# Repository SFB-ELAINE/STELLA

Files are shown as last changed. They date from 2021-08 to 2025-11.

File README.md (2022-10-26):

# The SofTware dEfined impLantabLe modular plAtform (STELLA) for preclinical deep brain stimulation

## Stimulation Platform

We aimed to develop an innovative neurostimulator that significantly increases animal welfare and DBS studies' scientific value. 

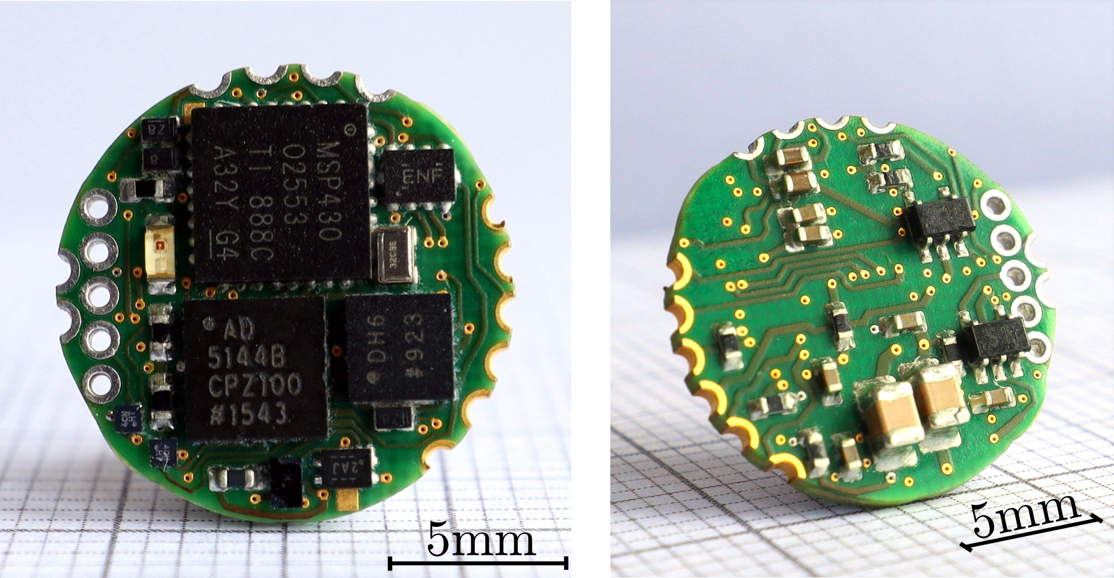
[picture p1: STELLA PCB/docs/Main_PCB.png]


Further details can be found at:

Franz Plocksties, Maria Kober, Christoph Niemann, Jakob Heller, Mareike Fauser, Martin Nüssel, Felix Uster, Denise Franz, Monique Zwar, Anika Lüttig, Justin Kröger, Jörg Harloff, Axel Schulz, Angelika Richter, Rüdiger Köhling, Dirk Timmermann, Alexander Storch:
The software defined implantable modular platform (STELLA) for preclinical deep brain stimulation research in rodents
In Journal of Neural Engineering, Vol. 18, Iss. 5, ISSN: 1741-2560, pp. 1-20, DOI: 10.1088/1741-2552/ac23e1, September 2021. https://iopscience.iop.org/article/10.1088/1741-2552/ac23e1

Hardware, software, and additional materials are available from here: [STELLA MAIN PCB](https://github.com/SFB-ELAINE/STELLA/tree/main/STELLA%20PCB)

## RF Shield

To link STELLA to the outside world, we have developed an energy-efficient RF Shield that operates in the ISM band. This shield can be piggybacked by STELLA, achieving a compact design. 

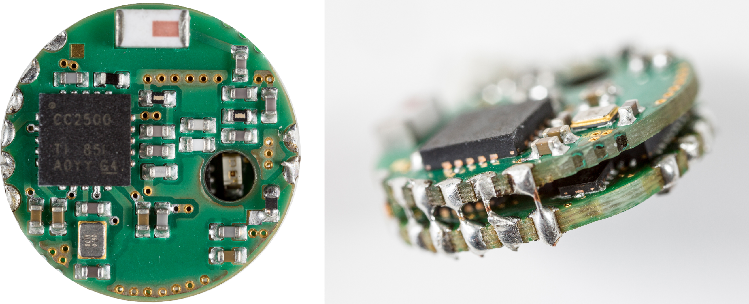
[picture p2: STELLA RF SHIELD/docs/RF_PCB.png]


Further details can be found at:

Franz Plocksties, Obaid Ullah Shah, Felix Uster, Munawar Ali, Maximilian Koschay, Maria Kober, Alexander Storch, Dirk Timmermann:
Energy-efficient modular RF interface for fully implantable electrical devices in small rodents
In Proceedings of the IEEE Biomedical Circuits and Systems Conference (BioCAS), pp. 1-6, DOI:10.1109/BioCAS49922.2021.9645022, Berlin, Deutschland, Oktober 2021. https://ieeexplore.ieee.org/document/9645022

Hardware, software, and additional materials are available from here: [STELLA RF SHIELD](https://github.com/SFB-ELAINE/STELLA/tree/main/STELLA%20RF%20SHIELD)

## Comparison of existing neurostimulators with STELLA

| | Ewing (2013) [56] | Kouzani (2017) [27] | Kölbl (2016) [26] | Fluri (2017) [24] | Pinnell (2018) [29] | Adams (2019) [21] | Harnack (2008) [32] | Fleischer (2020) [57] | de Haas (2012) [31] | Hentall (2013) [33] | Millard (2007) [34] | Forni (2012) [25] | Alpaugh (2019) [30] | Liu (2017) [28] | Arfin (2009) [22] | STELLA |
|---|---|---|---|---|---|---|---|---|---|---|---|---|---|---|---|---|
| Current amplitude (µA) | 13-1000 | 200 | 26-2036 | 10-500 | 20-2000 | -625 | 50-600 | up to 300 | 20-100 | 20-100 | 100-500 | 50-120 | 149 | 200-500 | 10-1000 | 42-100 |
| Pulse-width (µs) | 1µs-100% DC‡ | 90 | 0.5µs-100% DC‡ | 60-500 | 10µs-100% DC‡ | 20 (min) | 52 | 60-500 | 60 | 100-1000 | 25-250 | 0-80 | 103/111 | 30-1400 | 180 | 1µs-100% DC‡ |
| Frequency (Hz) | 2-500 | 130 | 10-300 | 10-200 | 0.1-5000 | 5000 (max) | 131 | 10-500 | 131 | 8, 16 or 24 | 50-5000 | 0-130 | 130 | 1-200 | 1400 (max) | 10-5000 |
| Inter-pulse delay (µs) | n/a | n/a | 60 | n/a | 0-pulse period | n/a | n/a | n/a | 200 | n/a | n/a | n/a | 103 | n/a | n/a | n/a |
| Compliance voltage (V) | 20 | 3 (battery) | 17 | 3.1 (battery) | 12 | 10 | 18 | 3.1 (battery) | 4.65 (battery) | 34 | 5 | 6 (battery) | 2,1 | 3 (battery) | 5 | 2.2-2.8 |
| No.  of channels | 2 | 1 | 1 | 1 | 2 | 1 | 1 | 1 | 2 | 1 | 1 | 1 | 1 | 1 | 4 | 2 |
| Charge balancing | Passive | Passive | Active | Passive | Active/Passive | Active | Active | Passive | Active | Passive | Active | n/a | Active | Passive | Active | Passive |
| Lifetime (DBS-on) | 10 days | 22 days | 6 days | 30 days | 30 hours | 9 hours | 28 days | 30 days | 10 hours | n/a (rests) | ∞ | 7 | 30 days | 3 months | 12 days | 126 days (CR1216), 241 days (CR1225) ¤ |
| Type of battery | ICP521630PM | CR2032 | 3xp675 | 2xV364 | CR1225 | CR2032 | 2xSR48 | 2xV364 | 3xSR416 | 2xSR41 | none, energy provided through inductive cage | 2xCR1220 | 2xSR48 | CR2032 | 2xML614 | CR1216, CR1220, CR1225, CR2032□ |
| Battery weight (g) | 5,4 | 3 | 3x1.8 | 2x0.3 | 0.9 | 3 | 2x1.1 | 2x0.3 | 3x0.13 | 2x0.6 | - | 2x0.8 | 2x1.1 | 3 | 2x0.16 | 0.6 (CR1216), 0.9 (CR1225) □ |
| PCB weight (g) | n/a | 0.92 | n/a | n/a | 0.8 | Feb 18 | n/a | n/a | n/a | n/a | n/a | n/a | n/a | n/a | n/a | 0.6 |
| Total stimulator weight (g) | 11.5¶ | 4.75§ | 13.8¶ | 2.5§ | 2.8¶ | 5§ | 13¶ | 2.8§ | 2.1¶ | 2¶ | 2.5{ | 5.6{/7.4¶ | 4.7¶ | 6§/16¶ | 1.3§ | 2.6 (CR1216), 4 (CR1225)¶ □ |
| Battery volume (mm3) | 3052 | 1000 | 3x550 | 2x70 | 300 | 1000 | 2x260 | 2x70 | 3x30 | 2x160 | - | 2x250 | 2x260 | 1000 | 2x50 | 200 (CR1216),300 (CR1225) □ |
| PCB size (mm) | n/a | 15x18x3* | 26x12x3* | n/a | Ø12.5x5 | 30x25x3* | 35x17.1x3* | 10x10x1 | 25x8x3* | n/a | n/a | 28x9x3* | n/a | Ø20x4 | 13x13x3* | Ø13x3.3 |
| PCB volume (mm3) | 2228 | 810 | 936 | 1477 | 613 | 2250 | 1796 | 130 | 600 | 688 | n/a | 756 | n/a | 1256 | 507 | 438 |
| PCB + battery volume (mm3)  | 5280 | 1810 | 2586 | 1617 | 913 | 3250 | 2316 | 270 | 690 | 1008 | - | 1256 | n/a | 2256 | 607 | 638 (CR1216), 738 (CR1225) □ |
| Total stimulator size (mm)  | 33x20x8¶ | 15x18x10*§ | 30x20x24*¶ | 21x11x7§ | Ø19.2x12.4¶ | 32.5x28x8§ | 38.5x20x13.5¶ | n/a | Ø8x30¶ | 18x8x7¶ | 14x12x6{ | 15x28x7¶ | n/a | Ø20x8¶ | n/a | Ø15.5×7.5 (CR1216), Ø17.0×9.0 (CR1225)¶ □ |
| Control medium | Magnet | Pushbutton | n/a | Jumper | Magnet | Magnet | Electromagn. | Magnet | Magnet | Magnet | Electromagn. | n/a | n/a | Electromagn. | Electromagn. | Magnet◆ |
| Output medium | Visual LED | Visual LED | n/a | Visual LED | Visual LED | Visual LED | Electromagn. | Visual LED | IR LED | IR LED | Visual LED | n/a | Visual LED | Electromagn. | Visual LED | Visual LED◆ |
| Status readout | ♣ | Programming status  | n/a | On/Off/♠ | On/Off | On/Off/♣ | Program var. | On/Off | On/Off/♠ | Program var. | On/Off | n/a | ♣ | On/Off/♣♠ | On/Off | On/Off/♣♠◆ |
| Mounting | Head or Back | Back | Head | Head | Head | Back | Implant | Implant | Head + Implant | Implant | Implant + cage | Head | Implant | Head | Head | Implant |
| Open source† | No | No | No | No | Complete | No | No | No | No | No | Incomplete | No | No | No | Incomplete | Complete |

*Estimated from photographic scale <br />
‡Duty Cycle <br />
Including §battery, {housing, ¶both <br />
†Including all design/layout/firmware files and datasets for reproduction <br />
¤ Refers to the stimulation parameters (1x100 µA, 130 Hz, 60 µs) for LPM3 at a boost voltage of 3.1 V  <br />
□ Highly flexible regarding needed stimulation time and rodent’s size and weight <br />
♣Battery voltage / ♠load impedance out of range indication <br />
◆ Extendable by inter-module communication <br />

## License

This project is licensed under the terms of GNU General Public License v3.0

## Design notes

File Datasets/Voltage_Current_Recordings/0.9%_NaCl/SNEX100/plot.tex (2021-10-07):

\documentclass[tikz]{standalone}

\usepackage{tikz}
\usepackage{circuitikz}
\usepackage{pgfplots}
\pgfplotsset{compat=1.14}

\pgfplotsset{
    compat=1.3, 
    every axis/.append style={scale only axis,
    height=2.25cm, width=2.5cm, xmin=-1, xmax=120,grid=major, x grid style={lightgray!92.02614379084967!black},
      y grid style={lightgray!92.02614379084967!black},tick align=outside, tick pos=left}
}

\pgfplotsset{every tick label/.append style={font=\footnotesize}, label style={font=\footnotesize}}
%\pgfplotsset{yticklabel style={text width=1em,align=right}}

\begin{document}
\begin{tikzpicture}
\definecolor{color0}{rgb}{0.12156862745098,0.466666666666667,0.705882352941177}

%%%%%%%%%%%%%%%%%%%%%%%%%%%%
%%%%%%%%  SNEX 100  %%%%%%%%
%%%%%%%%%%%%%%%%%%%%%%%%%%%%

%%%%%%% VOLTAGE %%%%%%%%

    \begin{axis}[%
    name=plot1,
    xticklabels={,,},
  %  xlabel={Time [$\mu$s]},
    ylabel={Voltage [V]},
    yticklabel style={text width=2em, align=right},
    xmin=-10,
    xmax=130,
   % ytick = {0, 0.4, 0.8},
    ymin=-0.1,
   ymax=0.8,
]
    \addplot[line width=1.0pt, color=color0] table [x=Time/us, y=Voltage/V, col sep=comma] {snex100_voltage_50uA_saline_no_discharge_resistance.csv};

    \addplot[line width=1.2pt, color=orange, dotted] table [x=Time/us, y=Voltage/V, col sep=comma] {snex100_voltage_50uA_saline_digital60_resistance.csv};
    \end{axis}

    \begin{axis}[%
    name=plot2,
  %  xlabel={Time [$\mu$s]},
   yticklabels={,,},
   xticklabels={,,},
    xmin=-10,
    xmax=130,
    ymin=-0.1,
    ymax=0.8,
    at=(plot1.right of south east), anchor=left of south west,
    ]
    \addplot[line width= 1.0pt, color=color0] table [x=Time/us, y=Voltage/V, col sep=comma] {snex100_voltage_100uA_saline_no_discharge_resistance.csv};

    \addplot[line width=1.2pt, color=orange, dotted] table [x=Time/us, y=Voltage/V, col sep=comma] {snex100_voltage_100uA_saline_digital60_resistance.csv};
    \end{axis}
    
%%%%%%% CURRENT %%%%%%%%
    
        \begin{axis}[%
    name=plot5,
    xlabel={Time [$\mu$s]},
    ylabel={Current [$\mu$A]},
    yticklabel style={text width=2em, align=right},
    xmin=-10,
    xmax=130,
    ymin=-380,
    ymax=130,
    ytick = {-200, 0, 50, 100},
  %  yticklabel style={rotate=-10},
   at=(plot1.below south west), anchor=above north west,
]
    \addplot[line width=1.0pt, color=color0] table [x=Time/us, y=Current/uA, col sep=comma] {snex100_current_50uA_saline_no_discharge_resistance.csv};

    \addplot[line width=1.2pt, color=orange, dotted] table [x=Time/us, y=Current/uA, col sep=comma] {snex100_current_50uA_saline_digital60_resistance.csv};
    \end{axis}
    
    \begin{axis}[%
    name=plot6,
    yticklabels={,,},
    xlabel={Time [$\mu$s]},
    xmin=-10,
    xmax=130,
    ymin=-380,
    ymax=130,    
    extra y ticks = {100},
    at=(plot5.right of south east), anchor=left of south west,
]
    \addplot[line width= 1.0pt, color=color0] table [x=Time/us, y=Current/uA, col sep=comma] {snex100_current_100uA_saline_no_discharge_resistance.csv};

    \addplot[line width=1.2pt, color=orange, dotted] table [x=Time/us, y=Current/uA, col sep=comma] {snex100_current_100uA_saline_digital60_resistance.csv};
    \end{axis}
    
%%%%%%%%%%%%%%%%%%%%%%%%%%%%
%%%%%%%%  Unipolar  %%%%%%%%
%%%%%%%%%%%%%%%%%%%%%%%%%%%%

%%%%%%% VOLTAGE %%%%%%%%

    \begin{axis}[%
    name=plot3,
    yticklabels={,,},
    xticklabels={,,},
%    xlabel={Time [$\mu$s]},
    %ylabel={Voltage [V]},
    xmin=-10,
    xmax=120,
    ymin=-0.1,
    ymax=0.8,
    at=(plot2.right of south east), anchor=left of south west,
    ]
    \addplot[line width= 1.0pt, color0] table [x=Time/us, y=Voltage/V, col sep=comma] {unipolar_voltage_50uA_saline_no_discharge_resistance.csv};

    \addplot[line width=1.2pt, color=orange, dotted] table [x=Time/us, y=Voltage/V, col sep=comma] {unipolar_voltage_50uA_saline_digital50_resistance.csv};

    \end{axis}
    
    \begin{axis}[%
    name=plot4,
    yticklabels={,,},
    xticklabels={,,},
%    xlabel={Time [$\mu$s]},
    %ylabel={Voltage [V]},
    xmin=-10,
    xmax=120,
    ymin=-0.1,
    ymax=0.8,
    at=(plot3.right of south east), anchor=left of south west,
    ]
    \addplot[line width= 1.0pt, color0] table [x=Time/us, y=Voltage/V, col sep=comma] {unipolar_voltage_100uA_saline_no_discharge_resistance.csv};

    \addplot[line width=1.2pt, color=orange, dotted] table [x=Time/us, y=Voltage/V, col sep=comma] {unipolar_voltage_100uA_saline_digital50_resistance.csv};

    \end{axis}
    
%%%%%%% CURRENT %%%%%%%%
   
    \begin{axis}[%
    name=plot7,
    yticklabels={,,},
    xlabel={Time [$\mu$s]},
    %ylabel={Current [$\mu$A]},
    xmin=-10,
    xmax=120,
    ymin=-380,
    ymax=130,
    extra y ticks = {50},
    at=(plot6.right of south east), anchor=left of south west,
    ]
    \addplot[line width= 1.0pt, color0] table [x=Time/us, y=Current/uA, col sep=comma] {unipolar_current_50uA_saline_no_discharge_resistance.csv};

    \addplot[line width= 1.2pt, color=orange, dotted] table [x=Time/us, y=Current/uA, col sep=comma] {unipolar_current_50uA_saline_digital50_resistance.csv};

    \end{axis}
    
    \begin{axis}[%
    name=plot8,
    yticklabels={,,},
    xlabel={Time [$\mu$s]},
    xmin=-10,
    xmax=120,
    ymin=-380,
    ymax=130,
    extra y ticks = {100},
    at=(plot7.right of south east), anchor=left of south west,
    ]
    \addplot[line width= 1.0pt, color0] table [x=Time/us, y=Current/uA, col sep=comma] {unipolar_current_100uA_saline_no_discharge_resistance.csv};

    \addplot[line width= 1.2pt, color=orange, dotted] table [x=Time/us, y=Current/uA, col sep=comma] {unipolar_current_100uA_saline_digital50_resistance.csv};

    \end{axis}

\draw [dashed, line width=0.8pt] (5.6,2.7) -- (5.6,-3.8);   

\node[align=center] at (2.7,2.5) {\small \textbf{Bipolar}};
\node[align=center] at (8.5,2.5) {\small \textbf{Unipolar}};

\node[align=center] at (2.25,2) {\footnotesize (a)};
\node[align=center] at (2.25,-0.7) {\footnotesize (b)};
\node[align=center] at (5.15,2) {\footnotesize (c)};
\node[align=center] at (5.15,-0.7) {\footnotesize (d)};
\node[align=center] at (8.05,2) {\footnotesize (e)};
\node[align=center] at (8.05,-0.7) {\footnotesize (f)};
\node[align=center] at (10.95,2) {\footnotesize (g)};
\node[align=center] at (10.95,-0.7) {\footnotesize (h)};

\end{tikzpicture}
\end{document}

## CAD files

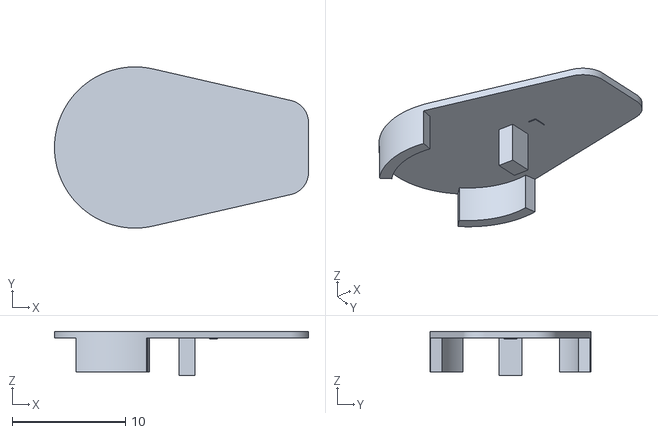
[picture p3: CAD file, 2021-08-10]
STELLA RF SHIELD/Encapsulation/Cap.stl
22.4 x 14.2 x 3.90

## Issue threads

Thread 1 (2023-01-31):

Parts list for PCB

skeltoh, 2023-01-31:
I am interested in building this - do you have a list of specific parts/manufacturers you used to assemble the pcb? I'm not sure if small details like thick/thin film resistors are important, and wanted to replicate it as closely as possible.

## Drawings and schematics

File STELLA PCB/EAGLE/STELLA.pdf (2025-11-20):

# A1 GND B¹ VCC A²

A

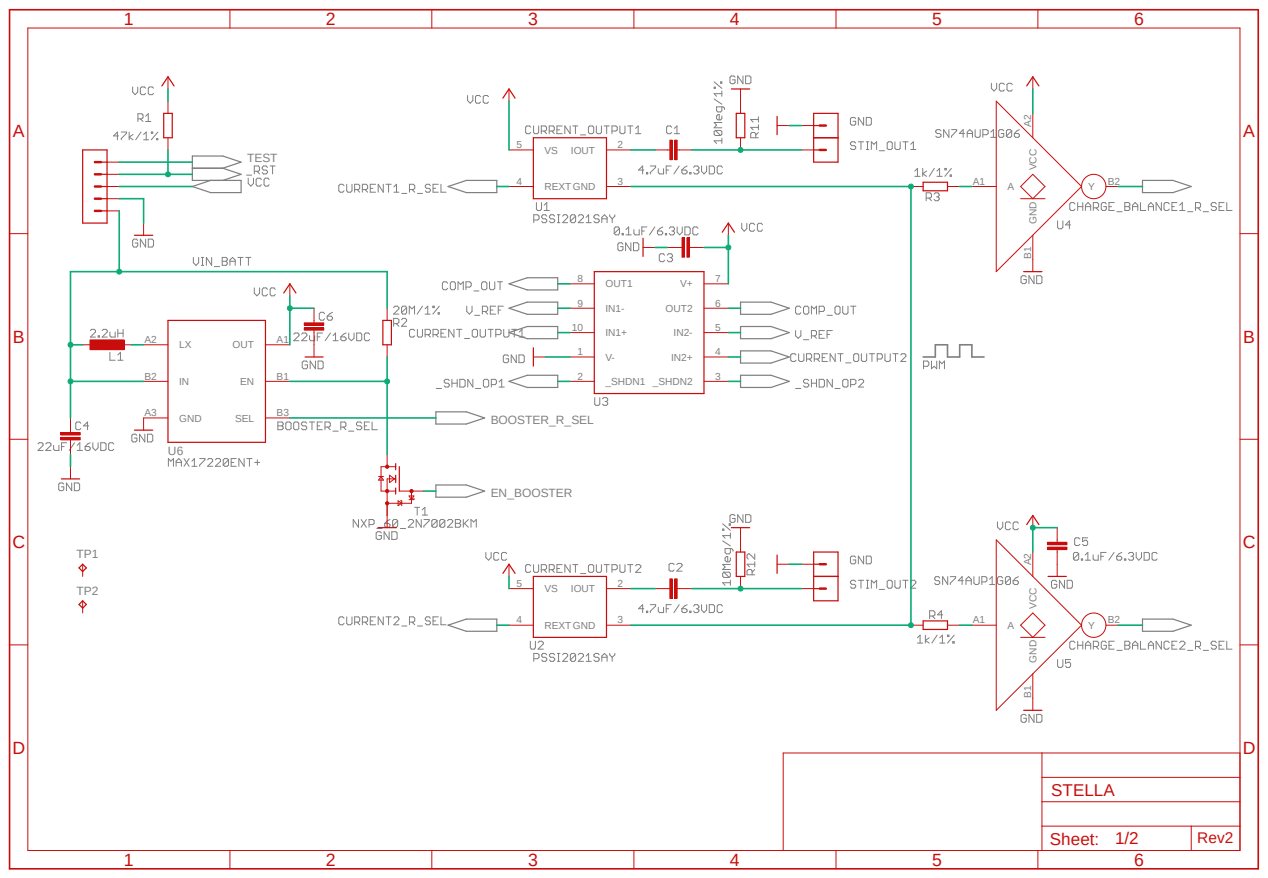
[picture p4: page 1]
GND; IOUT; REXT 4; OUT; SEL; GND A3; OUT1 8; OUT2; _SHDN1 2; _SHDN2; GND B¹ VCC A²; BOOSTER_R_SEL; EN_BOOSTER; TEST; Sheet:; Rev2; STELLA

# _WP 20 PAD 25

A

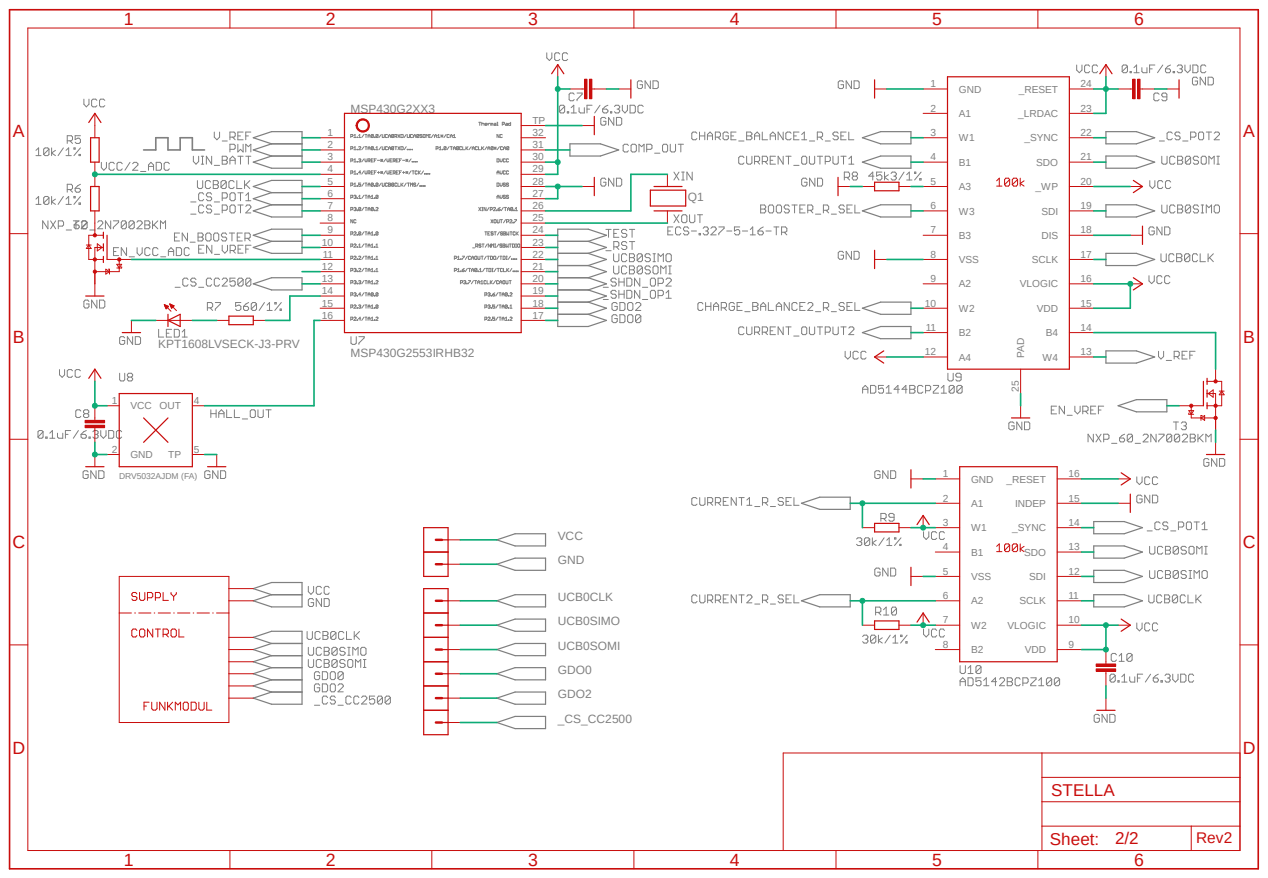
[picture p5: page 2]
MSP430G2553IRHB32; MSP430G2XX3; KPT1608LVSECK-J3-PRV; DRV5032AJDM (FA); DIS; GND 1; SCLK; SDI; SDO; VDD; VLOGIC; VSS 8; _LRDAC; _RESET; _SYNC; INDEP; VSS 5; GND 2; OUT 4; VCC 1; VCC; GND; UCB0CLK; UCB0SOMI; UCB0SIMO; GDO0; GDO2; Sheet:; Rev2; STELLA

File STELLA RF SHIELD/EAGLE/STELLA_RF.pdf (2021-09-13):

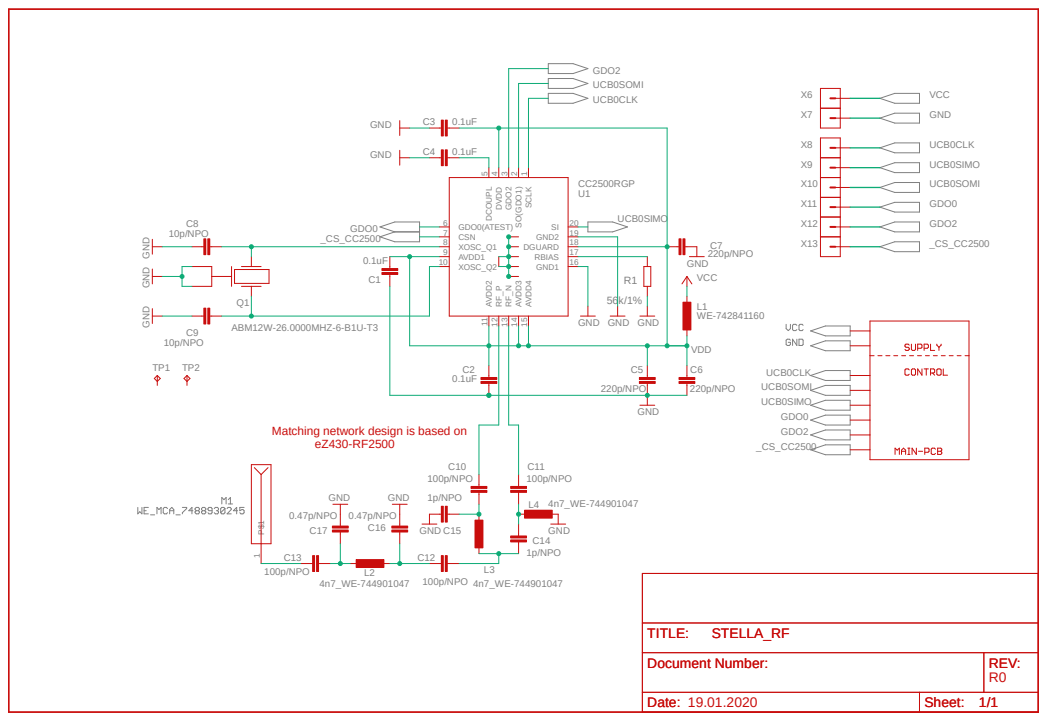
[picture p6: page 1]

Matching network design is based on

Document Number: | REV: REV: R0

Date: Date: 19.01.2020 | Sheet: Sheet: 1/1 1/1

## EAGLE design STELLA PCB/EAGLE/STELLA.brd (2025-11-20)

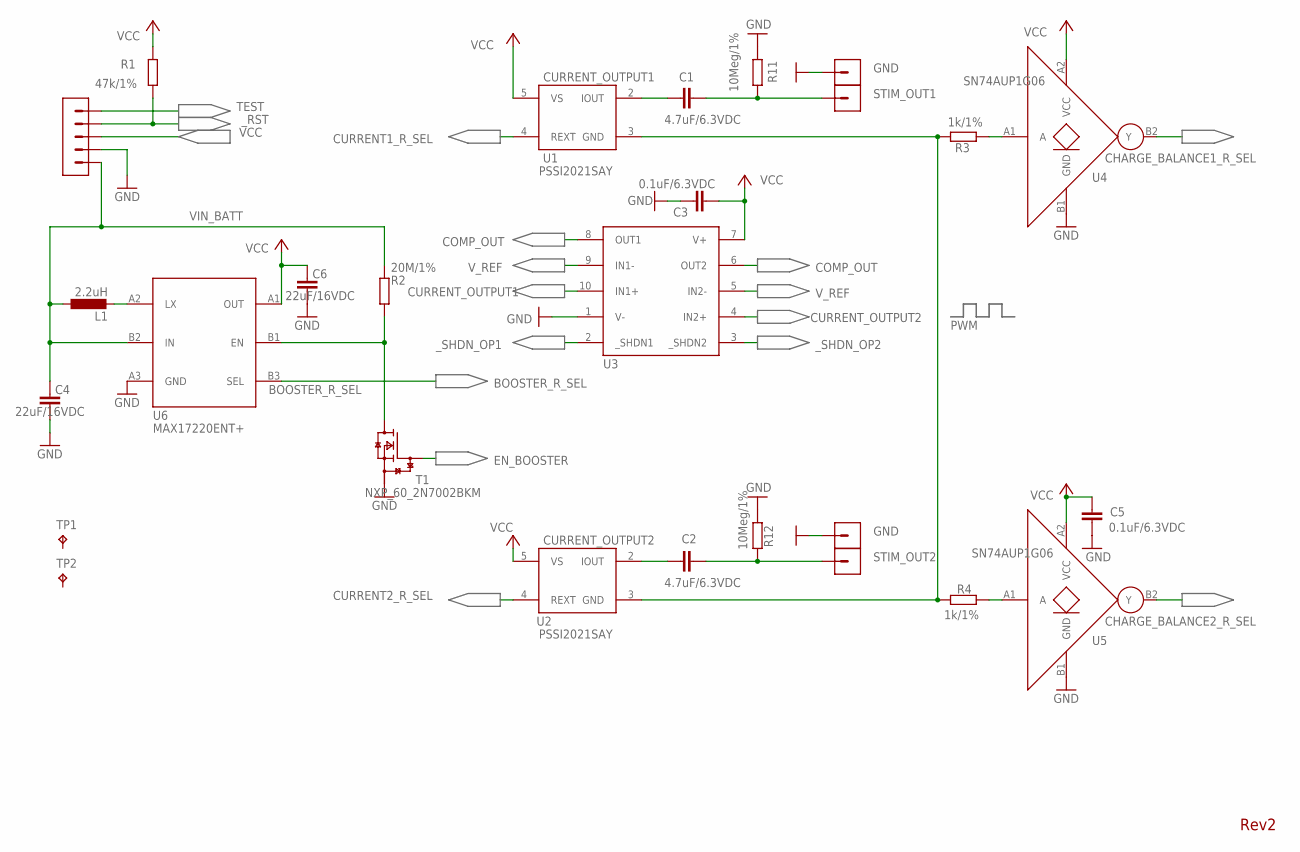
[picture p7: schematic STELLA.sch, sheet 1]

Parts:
C1, C2: 4.7uF/6.3VDC; C0402
C3, C5: 0.1uF/6.3VDC; C0402
C4, C6: 22uF/16VDC; MYRCL_0603
L1: 2.2uH; L0402
R1: 47k/1%; R0402
R2: 20M/1%; R0402
R3, R4: 1k/1%; R0402
R11, R12: 10Meg/1%; R0402
T1: NXP_60_2N7002BKM; NXP_60_SOT883(B)
TP1, TP2: TPTP06SQ; TP06SQ
U1, U2: PSSI2021SAY; SOT353
U3: TLV_9002S_TLV9002S_RUG
U4, U5: SN74AUP1G06; SN74AUP1G06_SN74AUP1G06YFPR
U6: MAX17220ENT+; MAX17220ENT
X1, X2, X3, X4: 1PIN_INTERFACE
X5: 5PIN; 0.9MM/0.6MM

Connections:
BOOSTER_R_SEL: U6.B3 (SEL); also elsewhere on the board
CHARGE_BALANCE1_R_SEL: U4.B2 (Y); also elsewhere on the board
CHARGE_BALANCE2_R_SEL: U5.B2 (Y); also elsewhere on the board
COMP_OUT: U3.6 (OUT2), U3.8 (OUT1); also elsewhere on the board
CURRENT1_R_SEL: U1.4 (REXT); also elsewhere on the board
CURRENT2_R_SEL: U2.4 (REXT); also elsewhere on the board
CURRENT_OUTPUT1: C1.2, U1.2 (IOUT), U3.10 (IN1+); also elsewhere on the board
CURRENT_OUTPUT2: C2.2, U2.2 (IOUT), U3.4 (IN2+); also elsewhere on the board
EN_BOOSTER: T1.1 (G); also elsewhere on the board
GND: C3.2, C4.2, C5.2, C6.2, R11.1, R12.2, T1.2 (S), U3.1 (V-), U4.B1 (GND), U5.B1 (GND), U6.A3 (GND), X2.1, X4.1, X5.2; also elsewhere on the board
unnamed: R2.1, T1.3 (D), U6.B1 (EN)
unnamed: L1.2, U6.A2 (LX)
unnamed: R3.1, U4.A1 (A)
unnamed: R4.1, U5.A1 (A)
PWM: R3.2, R4.2, U1.3 (GND), U2.3 (GND); also elsewhere on the board
STIM_OUT1: C1.1, R11.2, X1.1
STIM_OUT2: C2.1, R12.1, X3.1
TEST: X5.5; also elsewhere on the board
VCC: C3.1, C5.1, C6.1, R1.1, U1.5 (VS), U2.5 (VS), U3.7 (V+), U4.A2 (VCC), U5.A2 (VCC), U6.A1 (OUT), X5.3; also elsewhere on the board
VIN_BATT: C4.1, L1.1, R2.2, U6.B2 (IN), X5.1; also elsewhere on the board
V_REF: U3.5 (IN2-), U3.9 (IN1-); also elsewhere on the board
_RST: R1.2, X5.4; also elsewhere on the board
_SHDN_OP1: U3.2 (_SHDN1); also elsewhere on the board
_SHDN_OP2: U3.3 (_SHDN2); also elsewhere on the board

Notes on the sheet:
Rev2

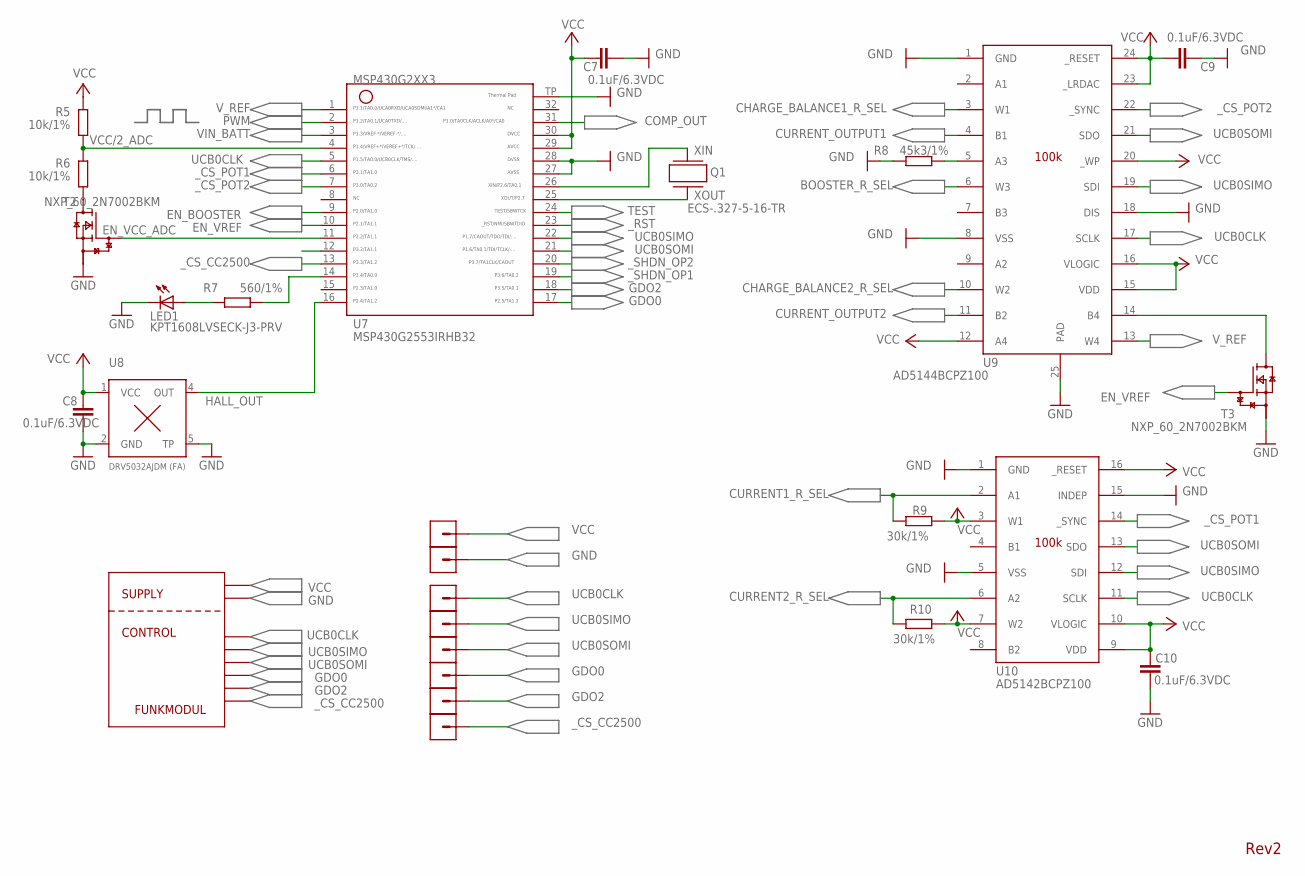
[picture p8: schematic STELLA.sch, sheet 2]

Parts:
C7, C8, C9, C10: 0.1uF/6.3VDC; C0402
LED1: KPT1608LVSECK-J3-PRV; LED_CHIP-LED0603
Q1: ECS-.327-5-16-TR; CRYSTAL_ECX_16_32768_ECX-16
R5, R6: 10k/1%; R0402
R7: 560/1%; R0402
R8: 45k3/1%; R0402
R9, R10: 30k/1%; R0402
T2, T3: NXP_60_2N7002BKM; NXP_60_SOT883(B)
U7: MSP430G2553IRHB32; RHB32
U8: DRV5032AJDM (FA); DRV5032_DRV5032_X2SON
U9: AD5144BCPZ100; AD5144_AD5144_LFCSP
U10: AD5142BCPZ100; AD5122_AD5142_LFCSP
X6, X7, X8, X9, X10, X11, X12, X13: 1PIN_INTERFACE

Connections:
BOOSTER_R_SEL: U9.6 (W3); also elsewhere on the board
CHARGE_BALANCE1_R_SEL: U9.3 (W1); also elsewhere on the board
CHARGE_BALANCE2_R_SEL: U9.10 (W2); also elsewhere on the board
COMP_OUT: U7.31; also elsewhere on the board
CURRENT1_R_SEL: R9.1, U10.2 (A1); also elsewhere on the board
CURRENT2_R_SEL: R10.2, U10.6 (A2); also elsewhere on the board
CURRENT_OUTPUT1: U9.4 (B1); also elsewhere on the board
CURRENT_OUTPUT2: U9.11 (B2); also elsewhere on the board
EN_BOOSTER: U7.9; also elsewhere on the board
EN_VCC_ADC: T2.1 (G), U7.11
EN_VREF: T3.1 (G), U7.10
GDO0: U7.17, X11.1
GDO2: U7.18, X12.1
GND: C7.2, C8.2, C9.1, C10.2, LED1.C, R8.2, T2.2 (S), T3.2 (S), U7.27, U7.28, U7.TP, U8.2 (GND), U8.5 (TP), U9.1 (GND), U9.8 (VSS), U9.18 (DIS), U9.25 (PAD), U10.1 (GND), U10.5 (VSS), U10.15 (INDEP), X7.1; also elsewhere on the board
HALL_OUT: U7.16, U8.4 (OUT)
unnamed: LED1.A, R7.2
unnamed: R6.2, T2.3 (D)
unnamed: R7.1, U7.14
unnamed: R8.1, U9.5 (A3)
unnamed: T3.3 (D), U9.14 (B4)
PWM: U7.2; also elsewhere on the board
TEST: U7.24; also elsewhere on the board
UCB0CLK: U7.5, U9.17 (SCLK), U10.11 (SCLK), X8.1
UCB0SIMO: U7.22, U9.19 (SDI), U10.12 (SDI), X9.1
UCB0SOMI: U7.21, U9.21 (SDO), U10.13 (SDO), X10.1
VCC: C7.1, C8.1, C9.2, C10.1, R5.1, R9.2, R10.1, U7.29, U7.30, U8.1 (VCC), U9.12 (A4), U9.15 (VDD), U9.16 (VLOGIC), U9.20 (_WP), U9.23 (_LRDAC), U9.24 (_RESET), U10.3 (W1), U10.7 (W2), U10.9 (VDD), U10.10 (VLOGIC), U10.16 (_RESET), X6.1; also elsewhere on the board
VCC/2_ADC: R5.2, R6.1, U7.4
VIN_BATT: U7.3; also elsewhere on the board
V_REF: U7.1, U9.13 (W4); also elsewhere on the board
XIN: Q1.1, U7.26
XOUT: Q1.2, U7.25
_CS_CC2500: U7.13, X13.1
_CS_POT1: U7.6, U10.14 (_SYNC)
_CS_POT2: U7.7, U9.22 (_SYNC)
_CS_POT3: U7.12
_RST: U7.23; also elsewhere on the board
_SHDN_OP1: U7.19; also elsewhere on the board
_SHDN_OP2: U7.20; also elsewhere on the board

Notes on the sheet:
100k
MSP430G2553IRHB32
ECS-.327-5-16-TR
FUNKMODUL
SUPPLY
CONTROL
VCC
GND
Rev2

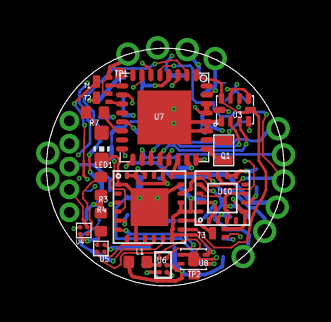
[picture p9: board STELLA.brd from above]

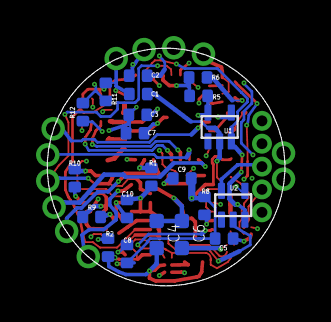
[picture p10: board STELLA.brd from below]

Board: 4 copper layers, 13.2 x 13.2 mm, 53 parts (21 on the bottom side), 43 nets.

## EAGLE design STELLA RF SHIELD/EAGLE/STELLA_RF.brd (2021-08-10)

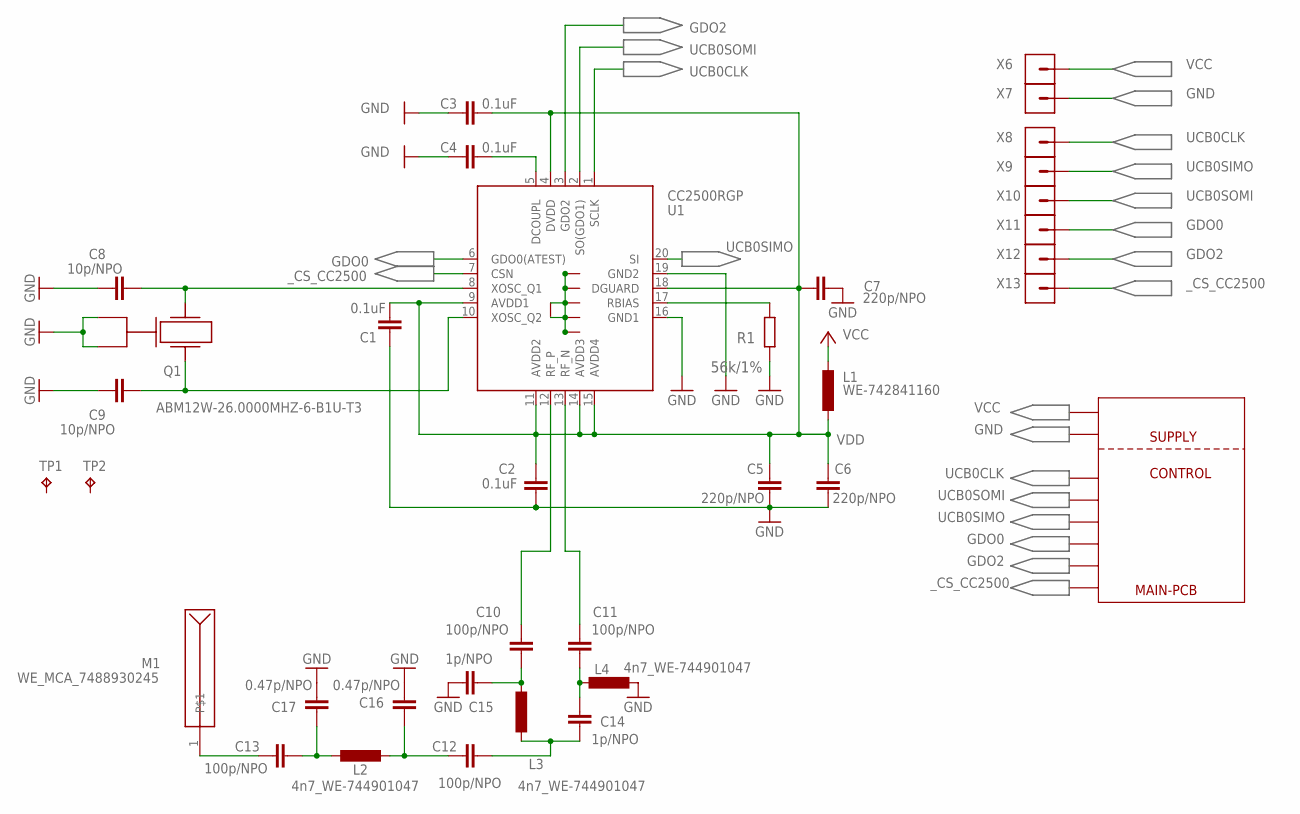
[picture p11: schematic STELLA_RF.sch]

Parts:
C1, C2, C3, C4: 0.1uF; C0402
C5, C6, C7: 220p/NPO; C0402
C8, C9: 10p/NPO; C0402
C10, C11, C12, C13: 100p/NPO; C0402
C14, C15: 1p/NPO; C0402
C16, C17: 0.47p/NPO; C0402
L1: WE-742841160; L0402
L2, L3, L4: 4n7_WE-744901047; L0402
M1: WE_MCA_7488930245
Q1: ABM12W-26.0000MHZ-6-B1U-T3; ABM12W
R1: 56k/1%; R0402
TP1, TP2: TPTP06SQ; TP06SQ
U1: CC2500RGP; CHIPCON_QLP20
X6, X7, X8, X9, X10, X11, X12, X13: 1PIN_INTERFACE

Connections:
GDO0: U1.6 (GDO0(ATEST)), X11.1
GDO2: U1.3 (GDO2), X12.1
GND: C1.1, C2.1, C3.1, C4.1, C5.1, C6.1, C7.2, C8.1, C9.1, C15.2, C16.2, C17.2, L4.1, Q1.2, Q1.4, R1.2, U1.16 (GND1), U1.19 (GND2), U1.EP, U1.GND1 (G1), U1.GND2 (G2), U1.GND3 (G3), U1.GND4 (G4), U1.GND5 (G5), X7.1
unnamed: C4.2, U1.5 (DCOUPL)
unnamed: C13.1, M1.1
unnamed: C8.2, Q1.1, U1.8 (XOSC_Q1)
unnamed: R1.1, U1.17 (RBIAS)
unnamed: C9.2, Q1.3, U1.10 (XOSC_Q2)
unnamed: C13.2, C17.1, L2.1
unnamed: C12.2, C16.1, L2.2
unnamed: C10.2, C15.1, L3.2
unnamed: C12.1, C14.2, L3.1
unnamed: C11.2, C14.1, L4.2
unnamed: C10.1, U1.12 (RF_P)
unnamed: C11.1, U1.13 (RF_N)
UCB0CLK: U1.1 (SCLK), X8.1
UCB0SIMO: U1.20 (SI), X9.1
UCB0SOMI: U1.2 (SO(GDO1)), X10.1
VCC: L1.1, X6.1
VDD: C1.2, C2.2, C3.2, C5.2, C6.2, C7.1, L1.2, U1.4 (DVDD), U1.9 (AVDD1), U1.11 (AVDD2), U1.14 (AVDD3), U1.15 (AVDD4), U1.18 (DGUARD)
_CS_CC2500: U1.7 (CSN), X13.1

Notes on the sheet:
WE_MCA_7488930245
SUPPLY
CONTROL
MAIN-PCB
VCC
GND
X10
X11
X12
X13

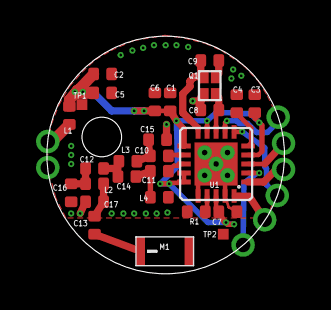
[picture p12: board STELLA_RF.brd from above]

Board: 2 copper layers, 13.2 x 13.2 mm, 35 parts (0 on the bottom side), 21 nets.

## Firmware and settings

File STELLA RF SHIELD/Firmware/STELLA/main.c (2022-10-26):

/******************************************
 * STELLA RF
 * Thanks to Obaid Ullah Shah for his main contribution to the firmware.
 * Supervision: Franz Plocksties / Dirk Timmermann
 ********************************************/

#include <msp430g2553.h>
#include <stdint.h>
#include <cc2500_reg.h>
#include <cc2500_val.h>
#include <string.h>
#include <stdio.h>
#include <stdlib.h>
#include "main.h"
#include "SPI.h"
#include "DigiPot.h"
#include "Booster.h"
#include "ADC.h"
#include "Comparator.h"
#include "BlinkPattern.h"
#include "cc2500.h"


volatile Stimulation_Status stimulationStatus = STIMULATION_OFF;
volatile int stimulation_cnt = 0;

volatile Battery_Status batteryLevel = BATTERY_LEVEL_NORMAL;

volatile Impedance_Status impedanceLeftStatus;
volatile Impedance_Status impedanceRightStatus;

volatile uint8_t ImpStL = 0x00, ImpStR = 0x00;

volatile Stimulation_Type type = BILATERAL;
volatile Stimulation_Channel channel = LATERAL_RIGHT; // only for UNILATERAL

volatile Power_Mode power_mode = SLEEP;
volatile Stimulation_CLK stimulation_clk;

volatile Function func = SET;


volatile uint8_t t_pac[9] = {0x00,0x00,0x00,0x00,0x00,0x00,0x00,0x00,0x00}; // Transmission Packet
int value;
int VBoostArray[16];
volatile uint8_t *p; // Initialize Pointer for Receiving packet
uint8_t data_new[16] = {0x00,0x00,0x00,0x00,0x00,0x00,0x00,0x00,0x00,0x00,0x00,0x00,0x00,0x00,0x09,0x00}; //testing for p[8 debug]
int k;

volatile uint8_t *imp;  //impedance status

const unsigned int repetition = 3;

volatile uint8_t pack_rec = 0x00;
volatile uint8_t pack_search = 0x00;
volatile uint8_t timer_decision = 0x00; // for timer
volatile uint16_t timer_counter = 0x0000; // counts upto 65535 and then transmit
volatile uint16_t txn_counter = 5400; // transmission cycle counter
volatile uint16_t timer_wor_counter = 90; // transmission cycle counter
volatile uint8_t gdo0_change = 0x00;
// real time clock variable
volatile uint8_t  rtc_hh = 12;
volatile uint8_t  rtc_mm = 00;
volatile uint8_t  rtc_ss = 00;

volatile int i_left; // keep the value of i_left for evaluating the proper boost voltage in bilateral stimulation

volatile int VRef_test_left;
volatile int VRef_test_right;
extern volatile int VRef_test;
volatile int i_new_imp;
extern volatile unsigned int timer_tar_count; // returning TAR counter value for DBS freq calculation
volatile unsigned timer_tar_count_left;
volatile unsigned timer_tar_count_right;
volatile unsigned timer_tar_PW_left;
volatile unsigned timer_tar_PW_right;
volatile unsigned long delay = 0x0000;//volatile uint16_t delay = 0x0000; //variable for delay cycles in comparator functions
volatile uint16_t Freq_compare = 0x0000;
extern unsigned int dbs_array[20]; //returning sampled values of DBS signal (used in comparator.c)

void EnableStimulation() {

    stimulationStatus = STIMULATION_ON;
    P1OUT &= ~BIT2;              // Enable the current source
    P1SEL |= BIT2;

}

void DisableStimulation() {

    stimulationStatus = STIMULATION_OFF;
    P1OUT |= BIT2;              // Disable the current source
    P1SEL &= ~BIT2;

}


void PWM(int freq, int pulse_width,  Power_Mode mode) {

    P1OUT &= ~BIT2;              // Enable the current source
    P1SEL |= BIT2;


    TA0CCTL1 = OUTMOD_7;        // CCR1 toggle/set

    if(mode == SLEEP) {
        //--------------------

        TA0CCR0 = freq;
        TA0CCR1 = pulse_width;
        //--------------------
        TA0CTL = TASSEL_2 + MC_1;   // SMCLK, up-down mode, 1MHz
    }

    else if(mode == DEEP_SLEEP) {

    P2SEL |= (BIT6 | BIT7); // Set P2.6 and P2.6 SEL for XIN, XOUT

        if(stimulation_clk == CLK_32kHz) {
            //----------------------------------------
            TA0CCR0 = freq;
            TA0CCR1 = pulse_width;
            //----------------------------------------
            TA0CTL = TASSEL_1 + MC_1;         // ACLK, upmode, 32 kHz}
        }

        else if(stimulation_clk == CLK_16kHz) {
            TA0CCR0 = DEEPSLEEP_16kHz_IMPLANT_TA0CCR0;
            TA0CCR1 = DEEPSLEEP_16kHz_IMPLANT_TA0CCR1;
            TA0CTL = TASSEL_1 + MC_1 + ID_1;         // ACLK, upmode, 16 kHz
}

}

}

void GDO0Setup() {

    // Set-up the HALL Sensor
    P2REN |= BIT5;               // Enable internal pull-up/down resistors
    P2OUT |= BIT5;              // Select pull-up mode for P2.5
    P2IES |= BIT5;              // P2.5 Hi/Lo edge
    P2IE  |= BIT5;
    P2IFG &= ~BIT5;              // P2.5 IFG cleared

}

void EnableGDO0() {

    P2OUT |= BIT5;  // Select pull-up mode for P2.5


}

void DisableGDO0() {

    P2OUT &= ~BIT5;  // Select pull-down mode for P2.5


}

void HallSensorSetup() {

    // Set-up the HALL Sensor
    P2REN |= BIT4;               // Enable internal pull-up/down resistors
    P2OUT |= BIT4;              // Select pull-up mode for P2.4
    P2IES |= BIT4;              // P2.4 Hi/Lo edge
    P2IE  |= BIT4;
    P2IFG &= ~BIT4;              // P2.4 IFG cleared

}

void ComparatorSetup()  {

    P1REN |= BIT0;               // Enable internal pull-up/down resistors
    P1OUT &= ~BIT0;              // Select pull-down mode for P1.0
    P1IE &= ~BIT0;                // don't listen to an interrupt for P1.0
    P1IES &= ~BIT0;              // 1.0 Lo/Hi edge
    P1IFG &= ~BIT0;              // P1.0 IFG cleared

}

void EnableHallSensor() {

    P2OUT |= BIT4;  // Select pull-up mode for P2.4


}

void DisableHallSensor() {

    P2OUT &= ~BIT4;  // Select pull-down mode for P2.4

}

void LEDSetup() {

    P3DIR |= BIT4;              // Status LED P3.4

}

uint16_t BatteryValue(){
    return CheckVBattery();
}

uint8_t ImpedanceStatus(int *VBoostArray, Stimulation_Channel channel, Stimulation_Type type, uint16_t Freq_compare, uint8_t pack_rec) {

    uint8_t status;


    int i;
    int i_right;
    Set_DIGIPOT(VBOOSTER,240); //default value Set_DIGIPOT(VBOOSTER,240);
    __delay_cycles(40000);


    if(type == UNILATERAL) {

        i = _compare(channel, VBoostArray, Freq_compare, pack_rec);
        __delay_cycles(100);

        if (i >= 0 && i < 16) {
            Set_DIGIPOT(VBOOSTER,i*16);
            i_new_imp = i*16;
            __delay_cycles(50000);
            return status = 0x00;
                }
        else if (i == -1)  {
             Set_DIGIPOT(VBOOSTER,0);
             i_new_imp = 0;
             __delay_cycles(50000);
            return status = 0x01;
                }
        else if (i == 16)  {
            Set_DIGIPOT(VBOOSTER,240);
            i_new_imp = 240;
            __delay_cycles(50000);
            return status = 0x02;
                }
    }


    else if(type == BILATERAL) {

        if(channel == LATERAL_LEFT)  {

            i_left = _compare(channel, VBoostArray, Freq_compare, pack_rec);

            if (i_left >= 0 && i_left < 16) return status = 0x00;
            else if (i_left == -1) return status = 0x01;
            else if (i_left == 16) return status = 0x02;
        }

        if(channel == LATERAL_RIGHT)  {

            i_right = _compare(channel, VBoostArray, Freq_compare, pack_rec);

            if(i_left == 16 || i_right == 16){
                Set_DIGIPOT(VBOOSTER,240);
                i_new_imp = 240;
            }
            else if(i_left == -1  && i_right == -1){
                Set_DIGIPOT(VBOOSTER,0);
                i_new_imp = 0;
            }
            else if(i_left < 16  && i_right < 16) {
                if(i_left > i_right)  {
                    Set_DIGIPOT(VBOOSTER,16*i_left);
                    i_new_imp = 16*i_left;
                }
                else {
                    Set_DIGIPOT(VBOOSTER, 16*i_right);
                    i_new_imp = 16*i_right;
                }
        }

            if (i_right >= 0 && i_right < 16) return status = 0x00;
            else if (i_right == -1) return status = 0x01;
            else if (i_right == 16) return status = 0x02;

        }

    }
return status;
}


uint8_t  *ImpChk(Stimulation_Type type, Stimulation_Channel channel, uint16_t Freq_compare, uint8_t pack_rec){
    uint8_t imps[2] = {0x03,0x03};
    if(type == BILATERAL) {

        imps[0] = ImpedanceStatus(VBoostArray, LATERAL_LEFT, BILATERAL, Freq_compare, pack_rec);
        VRef_test_left = VRef_test; //vref_return();
        if(imps[0]==0){
            timer_tar_count_left = dbs_freq(channel, Freq_compare); // for freq of DBS signal
            timer_tar_PW_left = dbs_pw(channel, Freq_compare); // for PW of DBS signal
        }
        imps[1] = ImpedanceStatus(VBoostArray, LATERAL_RIGHT, BILATERAL, Freq_compare, pack_rec);
        VRef_test_right = VRef_test; //vref_return();
        if(imps[1]==0){
            timer_tar_count_right = dbs_freq(channel, Freq_compare); // for freq of DBS signal
            timer_tar_PW_right = dbs_pw(channel, Freq_compare); // for PW of DBS signal
        }
    }

    else if(type == UNILATERAL && channel == LATERAL_LEFT) {

        imps[0] = ImpedanceStatus(VBoostArray, LATERAL_LEFT, UNILATERAL, Freq_compare, pack_rec);
        VRef_test_left = VRef_test; //vref_return();
        if(imps[0]==0){
            if(pack_rec == 1){
                sample_dbs(channel, VRef_test, Freq_compare); //just for testing
                timer_tar_count_left = dbs_freq(channel, Freq_compare); // for freq of DBS signal
                timer_tar_PW_left = dbs_pw(channel, Freq_compare); // for PW of DBS signal
            }
        }
        VRef_test_right = 0x00;
        timer_tar_count_right = 0; // for freq of DBS signal
        timer_tar_PW_right = 0;
    }
    else if(type == UNILATERAL && channel == LATERAL_RIGHT) {

        imps[1] = ImpedanceStatus(VBoostArray, LATERAL_RIGHT, UNILATERAL, Freq_compare, pack_rec);
        VRef_test_right = VRef_test; //vref_return();
        VRef_test_left = 0x00;
        if(imps[1]==0){
            if(pack_rec == 1){
                sample_dbs(channel, VRef_test, Freq_compare); //just for testing
                timer_tar_count_right = dbs_freq(channel, Freq_compare); // for freq of DBS signal
                timer_tar_PW_right = dbs_pw(channel, Freq_compare); // for PW of DBS signal
            }
        }
        timer_tar_count_left = 0; // for freq of DBS signal
        timer_tar_PW_left = 0;

    }

    return imps;
}

void setupTimer() {
    P2SEL |= (BIT6 | BIT7); // Set P2.6 and P2.6 SEL for XIN, XOUT
    TA1CCTL0 = CCIE;                             // CCR0 interrupt enabled
    TA1CCR0= 65535;
    TA1CTL = TASSEL_1 + MC_1;                  // ACLK, upmode
}

void count_rtc(){
    rtc_ss += 2;
    if(rtc_ss >= 60){
        rtc_ss = 0;
        if(++rtc_mm >= 60){
            rtc_mm = 0;
            if(++rtc_hh >= 24)
                rtc_hh = 0;
        }
    }
}

void ini_f_pw_variables(){
    timer_tar_count_left = 0;
    timer_tar_count_right = 0;
    timer_tar_PW_left = 0;
    timer_tar_PW_right = 0;
    dbs_array[0] = 0;
    dbs_array[1] = 0;
    dbs_array[2] = 0;
    dbs_array[3] = 0;
    dbs_array[4] = 0;
    dbs_array[5] = 0;
}

int main(void)  {
   //volatile Power_Mode p_mode = DEEP_SLEEP;
   volatile uint16_t FREQ=0x0000,PW=0x0000;
   volatile uint8_t Mode = 0x01;
   volatile uint8_t Stimulation = 0x00;
   volatile uint16_t tmp = 0x0000; //use to readout ADC value for temperature

   volatile uint16_t BatVal = 0x0000; // use to readout ADC value for battery
   volatile uint8_t RSSI_Value = 0x00; // use to readout RSSI register value for received packet
   volatile uint8_t Implant_ID = 0x01; // Implant id, it should be changed for every implant. Range 1-255

    WDTCTL = WDTPW | WDTHOLD;   // Stop watchdog timer

    BCSCTL1 = CALBC1_1MHZ;      /* Set DCO to 1MHz */
    DCOCTL = CALDCO_1MHZ;

    BCSCTL3 |= XCAP_1;              //5pF cap- setting for 32768Hz crystal


    P1OUT &= 0x00;              // Shut down everything
    P1DIR &= 0x00;
    P2OUT &= 0x00;
    P2DIR &= 0x00;
    P3OUT &= 0x00;
    P3DIR &= 0x00;

    P1SEL &= 0x00;              // select P1 for I/O
    P2SEL &= 0x00;              // select P2 for I/O
    P3SEL &= 0x00;              // select P3 for I/O

    P1OUT |= BIT2;              // Disable the current source
    P1DIR |= BIT2;

    if(power_mode == DEEP_SLEEP) stimulation_clk = CLK_32kHz;

    PORT_EN_VBOOST_FET_DIR |= EN_VBOOST_FET; // MOSFET for enable measuring the supply voltage (boost voltage)
    PORT_EN_VBOOST_FET_OUT &= ~EN_VBOOST_FET; // disable MOSFET for enable measuring the supply voltage (boost voltage)

    PORT_EN_VREF_FET_DIR |= EN_VREF_FET; // MOSFET for enable measuring the reference voltage adjusted by the AD5144 (100kOhm)
    PORT_EN_VREF_FET_OUT &= ~EN_VREF_FET; // disable MOSFET for enable measuring the reference voltage adjusted by the AD5144 (100kOhm)

    PORT_SHDN_OP1_DIR |= _SHDN_OP1;
    PORT_SHDN_OP2_DIR |= _SHDN_OP2;
    PORT_SHDN_OP1_OUT &= ~_SHDN_OP1; // disable OP left side
    PORT_SHDN_OP2_OUT &= ~_SHDN_OP2; // disable OP right side

    //------------------------

    HallSensorSetup(); // PWD (O)
    LEDSetup();
    ComparatorSetup();
    SPISetup();

    //------------------------
    //spi_init();
    UCB0CTL0 |= UCCKPH;
    cc2500_reset();
    cc2500_init();
    GDO0Setup();
    cc2500_nwor_init();
    pwd_mode_cc2500();
    DisableGDO0(); //very important to disable GDO0 for low current consumption
    //------------------------
        unsigned int VBoostCnt;
        int VBoostStep = 0; //

       for(VBoostCnt = 0; VBoostCnt < 16; VBoostCnt++) {

           Set_DIGIPOT(VBOOSTER, VBoostStep);
           __delay_cycles(300000);
           VBoostArray[VBoostCnt] = CheckVBoost(); // Obaid
           VBoostStep += 16;

        }


    Set_DIGIPOT(VBOOSTER, 0);
    __delay_cycles(300000);
    Set_DIGIPOT(COUNTERPULSE_ATTENUATION_LEFT, 0); // charge balancing resistance
    Set_DIGIPOT(COUNTERPULSE_ATTENUATION_RIGHT, 0); // charge balancing resistance
    Set_DIGIPOT(CURRENT_LEFT, 50);
    Set_DIGIPOT(CURRENT_RIGHT, 50);
    Set_DIGIPOT(VREF, 0);
    EnableHallSensor(); // PWD (O)
    DisableStimulation();
    StimulationOffPattern();
    setupTimer(); //Inclusion of second timer. Setup only
    CheckVBoostNew(); //just for testing of current reduction with 1.5v start
    BatteryValue(); //just for testing of current reduction with 1.5v start

   //------------------------
    while(1) {
        __bis_SR_register(LPM3_bits + GIE);       // Enter LPM3 w/ interrupt
        if(timer_counter >= txn_counter || timer_decision == 1){
            if(timer_counter >= txn_counter){
                timer_counter = 0;
                pack_rec = 0x00;
                //write transmit code
                volatile uint8_t t_pac[13] = {0x00,0x00,0x00,0x00,0x00,0x00,0x00,0x00,0x00,0x00,0x00,0x00,0x00}; // Transmission Packet
                ContinuousTxnPattern(); // just for testing, can be removed later
                GDO0Setup();
                DisableHallSensor(); //for testing on 11.03.2021 problem in swiping magnet after setting parameters
                UCB0CTL0 |= UCCKPH;
                UCB0CTL1 &= ~UCSWRST; //added for testing
                __delay_cycles(10000);
                DisableGDO0();  // Disable GDO interrupt while Transmitting data
                SPI_writeData(CC2500, REG_CHANNR,   0x00);
                pwd_mode_cc2500(); //PWD (O) 110321
                stimulationStatus = (Stimulation_Status)data_new[5];  // Stimulation ON or OFF
                if (stimulationStatus == STIMULATION_OFF){
                    DisableStimulation();
                    Set_DIGIPOT(VBOOSTER, 0); //ADDED 23.11
                    __delay_cycles(600000); // Added 23.11
                    tmp=temp_read();    // Reading temperature
                    t_pac[0] = 0x00 | tmp;  // breaking temperature value in to bytes for SPI transmission
                    t_pac[1] = 0x00 | tmp >> 8;
                    t_pac[3] = 0x03;          // Left Lateral Impedance
                    t_pac[4] = 0x03;          // Right Lateral Impedance
                    uint16_t VBoost_value = CheckVBoostNew();
                    BatVal = BatteryValue();
                    t_pac[2] = 0x00 | BatVal;  // breaking voltage value in to bytes for SPI transmission
                    t_pac[5] = 0x00 | BatVal >> 8;
                    t_pac[6] = 0x00 | VBoost_value;
                    t_pac[7] = 0x00 | VBoost_value >> 8;
                    UCB0CTL0 |= UCCKPH;
                    UCB0CTL1 &= ~UCSWRST;                           // **Initialize USCI state machine**
                    __delay_cycles(40000); // just for testing
                    awake_cc2500(); //110321
                    __delay_cycles(4000); // just for testing
                    //t_pac[8] = 0x00;  // RSSI Obaid
                    t_pac[8] = 0x00;
                    t_pac[9] = 0x00;
                    t_pac[10] = Implant_ID;
                    t_pac[11] = rtc_hh;
                    t_pac[12] = rtc_mm;
                    cc2500_transmit_arr(13,t_pac);
                    SPI_writeData(CC2500, REG_CHANNR,   VAL_CHANNR);
                    EnableGDO0(); // Enable GDO interrupt after transmission
                }
                else if(stimulationStatus == STIMULATION_ON){
                    FREQ = data_new[1]<<8 | data_new[0];      // Getting Frequency Values
                    PW =  data_new[3]<<8| data_new[2];        //Getting PWM ON-time Value
                    Freq_compare = FREQ; // using for delay function. At moment in testing phase
                    Mode = data_new[4];                // Sleep or Deep Sleep mode
                    power_mode = (Power_Mode)Mode;
                    type = (Stimulation_Type)data_new[7];          // Bilateral or Uni-lateral //testing
                    channel = (Stimulation_Channel)data_new[8];       // Left or Right Channel //testing
                    Set_DIGIPOT(COUNTERPULSE_ATTENUATION_LEFT, data_new[9]); // charge balancing resistance
                    Set_DIGIPOT(COUNTERPULSE_ATTENUATION_RIGHT, data_new[9]); // charge balancing resistance
                    Set_DIGIPOT(CURRENT_LEFT, data_new[10]);
                    Set_DIGIPOT(CURRENT_RIGHT, data_new[10]);
                    PWM(FREQ, PW,(Power_Mode)Mode);
                    EnableStimulation();
                    __delay_cycles(10000); // for testing 23.11
                    tmp=temp_read();    // Reading temperature
                    t_pac[0] = 0x00 | tmp;  // breaking temperature value in to bytes for SPI transmission
                    t_pac[1] = 0x00 | tmp >> 8;
                    pack_rec = 0x00;
                    imp=ImpChk(type,channel,Freq_compare, pack_rec);   // impedance status
                    t_pac[3] = imp[0];          // Left Lateral Impedance
                    t_pac[4] = imp[1];          // Right Lateral Impedance
                    rtc_ss++; // adding offset because timer was stopped for approximately 1.266 secs
                    rtc_ss++;
                    setupTimer(); // again setup the timer
                    __delay_cycles(900000);
                    uint16_t VBoost_value = CheckVBoostNew();
                    BatVal = BatteryValue();
                    t_pac[2] = 0x00 | BatVal;  // breaking voltage value in to bytes for SPI transmission
                    t_pac[5] = 0x00 | BatVal >> 8;
                    t_pac[6] = 0x00 | VBoost_value;
                    t_pac[7] = 0x00 | VBoost_value >> 8;
                    Set_DIGIPOT(VBOOSTER, 0); //ADDED 23.11
                    UCB0CTL0 |= UCCKPH; //110321
                    UCB0CTL1 &= ~UCSWRST;                           // **Initialize USCI state machine**
                    __delay_cycles(40000); // just for testing
                    awake_cc2500(); //110321
                    __delay_cycles(4000); // just for testing
                    t_pac[8] = VRef_test_left;
                    t_pac[9] = VRef_test_right;
                    t_pac[10] = Implant_ID;
                    t_pac[11] = rtc_hh;
                    t_pac[12] = rtc_mm;
                    UCB0CTL0 |= UCCKPH;
                    UCB0CTL1 &= ~UCSWRST;                           // **Initialize USCI state machine**
                    cc2500_transmit_arr(13,t_pac);
                    SPI_writeData(CC2500, REG_CHANNR,   VAL_CHANNR);
                    EnableGDO0(); // Enable GDO interrupt after transmission
                    Set_DIGIPOT(VBOOSTER, i_new_imp); //to adjust VBooster to proper value
                    __delay_cycles(300000);
                }
                pack_rec = 0;
                UCB0CTL0 |= UCCKPH;
                UCB0CTL1 &= ~UCSWRST;                           // **Initialize USCI state machine**
                pwd_mode_cc2500(); //PWD (O)
                DisableGDO0(); // PWD (O)
                EnableHallSensor(); // PWD (O)
                timer_decision = 0;
                ini_f_pw_variables(); // re-initialize f and pw variables
//                setupTimer(); //TA1CTL = MC_1;                  // start timer
            }
            else if(timer_decision == 0x01){ //(timer_decision == 0x01)

                //volatile uint8_t t_pac[22] = {0x00,0x00,0x00,0x00,0x00,0x00,0x00,0x00,0x00,0x00,0x00,0x00,0x00,0x00}; // Transmission Packet
                volatile uint8_t t_pac_new[34] = {0x00,0x00,0x00,0x00,0x00,0x00,0x00,0x00,0x00,0x00,0x00,0x00,0x00,0x00,0x00,0x00,0x00,0x00,0x00,0x00,0x00,0x00,0x00,0x00,0x00,0x00,0x00,0x00,0x00,0x00,0x00,0x00,0x00,0x00};
                DisableHallSensor();

                Set_DIGIPOT(VREF, 0); //added 11.05.21 for minimum voltage
                __delay_cycles(500000); // for easy detection of wor on pattern after enabling it 23.11
                StartErrorRecognitionPattern();  // just for testing, can be removed later
                __delay_cycles(10000); // delay for voltage stabilization
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

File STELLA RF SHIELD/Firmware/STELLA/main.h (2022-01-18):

#ifndef MAIN_H_
#define MAIN_H_

#define SLEEP_MODE = 0x00
#define DEEP_SLEEP_MODE = 0x01

#define BATTERY_VOLTAGE_THRESHOLD   2600    // 2.6V

#define IMPLANT_FREQUENCY           130     // Hz
#define IMPLANT_PULSE_WIDTH         60      // us
#define IMPLANT_PERIOD              8000       // us

#define SLEEP_IMPLANT_TA0CCR0             7691    // (1000000 / IMPLANT_FREQUENCY - 1)
#define SLEEP_IMPLANT_TA0CCR1             7631    // (1000000 / IMPLANT_FREQUENCY - 1 - IMPLANT_PULSE_WIDTH)

#define DEEPSLEEP_32kHz_IMPLANT_TA0CCR0             252    // (1000000 / IMPLANT_FREQUENCY - 1)
#define DEEPSLEEP_32kHz_IMPLANT_TA0CCR1             251    // (1000000 / IMPLANT_FREQUENCY - 1 - IMPLANT_PULSE_WIDTH)

#define DEEPSLEEP_16kHz_IMPLANT_TA0CCR0            126    // (1000000 / IMPLANT_FREQUENCY - 1)
#define DEEPSLEEP_16kHz_IMPLANT_TA0CCR1            126    // (1000000 / IMPLANT_FREQUENCY - 1 - IMPLANT_PULSE_WIDTH)

typedef enum {
    BATTERY_LEVEL_NORMAL,
    BATTERY_LEVEL_LOW
} Battery_Status;

typedef enum {
    LATERAL_LEFT,
    LATERAL_RIGHT,

} Stimulation_Channel;

typedef enum {
    UNILATERAL,
    BILATERAL
} Stimulation_Type;


typedef enum {
    IMPEDANCE_NORMAL,
    IMPEDANCE_LOW,
    IMPEDANCE_HIGH
} Impedance_Status;


typedef enum {
    CURRENT_LEFT,
    CURRENT_RIGHT,
    COUNTERPULSE_ATTENUATION_LEFT,
    COUNTERPULSE_ATTENUATION_RIGHT,
    VBOOSTER,
    VREF
} Digipot_Function;


typedef enum {
    SLEEP,
    DEEP_SLEEP
} Power_Mode;


typedef enum {
    CLK_32kHz,
    CLK_16kHz
} Stimulation_CLK;


typedef enum {
    STIMULATION_OFF,
    STIMULATION_ON
} Stimulation_Status;



typedef enum {
    AD5144,
    AD5142,
    CC2500
} AD_Type;

typedef enum {
    GET,
    SET
} Function;

void delay_ms(unsigned int delay);
#endif

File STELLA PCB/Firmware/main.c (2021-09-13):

/*
 * P1.0 : COMP1 SIGNAL LEFT && COMP2 SIGNAL RIGHT gated by SHDN-Pins
 * P1.1 : VREF ADC
 * P1.2 : PWM
 * P1.3 : VBattery ADC
 * P1.4 : VDD ADC
 * P1.5 : UCB0CLK
 * P1.6 : UCB0SOMI
 * P1.7 : UCB0SIMO
 *
 * P2.0 : EN_BOOSTER
 * P2.1 : EN_VREF_FET
 * P2.2 : EN_VBOOST_FET
 * P2.3 : ---
 * P2.4 : HALL OUT
 * P2.5 : GDO0
 * P2.6 : XIN
 * P2.7 : XOUT
 *
 * P3.0 : _CS_AD5144 (CounterPulse Attenuation Left && Right, Boost Voltage, Reference Voltage)
 * P3.1 : _CS_AD5142 (Current Adjustment)
 * P3.2 : ---
 * P3.3 : _CS_CC2500
 * P3.4 : LED
 * P3.5 : GDO2
 * P3.6 : _SHDN_OPV_P1.0
 * P3.7 : _SHDN_OPV_P1.1
 *
 * */

#include <msp430g2553.h>
#include "main.h"
#include "SPI.h"
#include "DigiPot.h"
#include "Booster.h"
#include "ADC.h"
#include "Comparator.h"
#include "BlinkPattern.h"


volatile Stimulation_Status stimulationStatus = STIMULATION_OFF;
volatile int stimulation_cnt = 0;

volatile Battery_Status batteryLevel = BATTERY_LEVEL_NORMAL;

volatile Impedance_Status impedanceLeftStatus;
volatile Impedance_Status impedanceRightStatus;

volatile Stimulation_Type type = BILATERAL; // STIM_OUT2 = CHAN_LEFT, STIM_OUT1 = CHAN_RIGHT
volatile Stimulation_Channel channel = CHAN_LEFT; // only for UNILATERAL
volatile Timer_Resolution timer_resolution = RESOLUTION_LOW;

volatile BIST_Status bist_status = BIST_ON; // Built-In Self-Test

unsigned int VBoostMax;
unsigned int VBoostMin;

unsigned int low_battery_cnt;
const unsigned int battery_check_cnt = 10;


void EnableStimulation() {

    stimulationStatus = STIMULATION_ON;

    if(timer_resolution == RESOLUTION_LOW) {
    P1OUT &= ~BIT2;              // Enable the current source
    P1SEL |= BIT2;
    }

    else if(timer_resolution == RESOLUTION_HIGH) TA1CTL = TASSEL_1 + MC_1;                    // Enable Timer1

    stimulation_cnt = 0;

}

void DisableStimulation() {

    stimulationStatus = STIMULATION_OFF;

    if(timer_resolution == RESOLUTION_LOW) P1SEL &= ~BIT2;

    else if(timer_resolution == RESOLUTION_HIGH) { // disable timers

    TA0CTL &= ~(MC_1);
    TA1CTL &= ~(MC_1);

    }

    P1OUT |= BIT2;              // Disable the current source
    StimulationOffPattern();
    stimulation_cnt = 0;
    Set_DIGIPOT(VBOOSTER, 0);
    _BIS_SR(LPM4_bits + GIE);
}


void PWM(int freq, int pulse_width) {


    P2SEL |= (BIT6 | BIT7); // Set P2.6 and P2.6 SEL for XIN, XOUT


    if (timer_resolution == RESOLUTION_LOW) {

        P1OUT &= ~BIT2;              // Enable the current source
        P1SEL |= BIT2;

        TA0CCTL1 = OUTMOD_7; // CCR1 toggle/set

        TA0CCR0 = FREQ_32kHz_IMPLANT_TA0CCR0;
        TA0CCR1 = FREQ_32kHz_IMPLANT_TA0CCR1;
        TA0CTL = TASSEL_1 + MC_1;         // ACLK, upmode, 32 kHz}
    }

    else if (timer_resolution == RESOLUTION_HIGH) {


        TA1CCTL0 = CCIE;                             // CCR0 interrupt enabled
        TA1CCR0 = 251 ;                             // set ControlRegister0 to the desired PWM frequency
//        TA1CTL = TASSEL_1 + MC_1;                    // ACLK, upmode, 32 kHz

        TA0CCTL0 = CCIE;  // T0 responsible for pulse width
        TA0CCR0 = 60;

        __enable_interrupt();

    }
}

void HallSensorSetup() {

    // Set-up the HALL Sensor
    P2REN |= BIT4;               // Enable internal pull-up/down resistors
    P2OUT |= BIT4;              // Select pull-up mode for P2.4
    P2IES |= BIT4;              // P2.4 Hi/Lo edge
    P2IE  |= BIT4;
    P2IFG &= ~BIT4;              // P2.4 IFG cleared

}

void ComparatorSetup()  {

    P1REN |= BIT0;               // Enable internal pull-up/down resistors
    P1OUT &= ~BIT0;              // Select pull-down mode for P1.0
    P1IE &= ~BIT0;                // don't listen to an interrupt for P1.0
    P1IES &= ~BIT0;              // 1.0 Lo/Hi edge
    P1IFG &= ~BIT0;              // P1.0 IFG cleared

}

void EnableHallSensor() {

    P2OUT |= BIT4;  // Select pull-up mode for P2.4

}

void DisableHallSensor() {

    P2OUT &= ~BIT4;  // Select pull-down mode for P2.4

}

void LEDSetup() {

    P3DIR |= BIT4;              // Status LED P3.4
}


int main(void)  {

    WDTCTL = WDTPW | WDTHOLD;   // Stop watchdog timer

    BCSCTL1 = CALBC1_1MHZ;      /* Set DCO to 1MHz */
    DCOCTL = CALDCO_1MHZ;

    BCSCTL3 |= XCAP_1;              //5pF cap- setting for 32768Hz crystal


    P1OUT &= 0x00;              // Shut down everything
    P1DIR &= 0x00;
    P2OUT &= 0x00;
    P2DIR &= 0x00;
    P3OUT &= 0x00;
    P3DIR &= 0x00;

    P1SEL &= 0x00;              // select P1 for I/O
    P2SEL &= 0x00;              // select P2 for I/O
    P3SEL &= 0x00;              // select P3 for I/O

    P1OUT |= BIT2;              // Disable the current source
    P1DIR |= BIT2;

    PORT_EN_VBOOST_FET_DIR |= EN_VBOOST_FET; // MOSFET for enable measuring the supply voltage (boost voltage)
    PORT_EN_VBOOST_FET_OUT &= ~EN_VBOOST_FET; // disable MOSFET for enable measuring the supply voltage (boost voltage)

    PORT_EN_VREF_FET_DIR |= EN_VREF_FET; // MOSFET for enable measuring the reference voltage adjusted by the AD5144 (100kOhm)
    PORT_EN_VREF_FET_OUT &= ~EN_VREF_FET; // disable MOSFET for enable measuring the reference voltage adjusted by the AD5144 (100kOhm)

    PORT_SHDN_OP1_DIR |= _SHDN_OP1;
    PORT_SHDN_OP2_DIR |= _SHDN_OP2;
    PORT_SHDN_OP1_OUT &= ~_SHDN_OP1; // disable OP left side
    PORT_SHDN_OP2_OUT &= ~_SHDN_OP2; // disable OP right side

    HallSensorSetup();
    LEDSetup();
    ComparatorSetup();
    SPISetup();

    int VBoostArray[16];
    unsigned int VBoostCnt;
    int VBoostStep = 0;

   for(VBoostCnt = 0; VBoostCnt < 16; VBoostCnt++) {

       Set_DIGIPOT(VBOOSTER, VBoostStep);
       __delay_cycles(300000);
       VBoostArray[VBoostCnt] = CheckVBoost();
       VBoostStep += 16;

    }

   // Booster Voltages:
   //  VBOOSTER = 0 --> 3.07 V
   //  VBOOSTER == 16 --> 3.07 V
   // VBOOSTER == 32 --> 3.07 V
   // VBOOSTER == 48 --> 3.07 V
   // VBOOSTER = 64 --> 3.17 V
   // VBOOSTER = 80 --> 3.17 V
   // VBOOSTER = 96 --> 3.17 V
   // VBOOSTER = 112 --> 3.27 V
   // VBOOSTER = 128 --> 3.27 V
   // VBOOSTER = 144 --> 3.27 V
   // VBOOSTER = 160 --> 3.38 V
   // VBOOSTER = 176 --> 3.38 V
   // VBOOSTER = 192 --> 3.48 V
   // VBOOSTER = 208 --> 3.48 V
   // VBOOSTER = 224 --> 3.58 V
   // VBOOSTER = 240 --> 3.68 V


    VBoostMax = VBoostArray[15];
    VBoostMin = VBoostArray[0];

    Set_DIGIPOT(VBOOSTER,0); // VBoostArray[15]
    __delay_cycles(300000);


    Set_DIGIPOT(COUNTERPULSE_ATTENUATION_LEFT, 0); // charge balancing resistance
    Set_DIGIPOT(COUNTERPULSE_ATTENUATION_RIGHT, 0); // charge balancing resistance
    Set_DIGIPOT(CURRENT_LEFT, 111); //  @3V: 0 == 44 uA, 111 == 50uA, 228 == 100 uA, 245 == 200 uA, 254 = 1.16 mA, 255 = 3.7 mA
    Set_DIGIPOT(CURRENT_RIGHT, 111); // @3V: 0 == 44 uA, 111 == 50uA, 228 == 100 uA, 245 == 200 uA, 254 = 1.16 mA, 255 = 3.6 mA
    Set_DIGIPOT(VREF, 0);


    EnableHallSensor();
    __bis_SR_register(LPM4_bits + GIE); // Stimulation off
    DisableHallSensor();
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

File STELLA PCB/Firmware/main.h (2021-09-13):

#ifndef MAIN_H_
#define MAIN_H_

#define BATTERY_VOLTAGE_THRESHOLD 2400   // 2.4V

#define IMPLANT_FREQUENCY         130     // Hz
#define IMPLANT_PULSE_WIDTH       60      // us
#define IMPLANT_PERIOD            8000       // us

//#define IMPLANT_TA0CCR0         7691    // (1000000 / IMPLANT_FREQUENCY - 1)
//#define IMPLANT_TA0CCR1         7631    // (1000000 / IMPLANT_FREQUENCY - 1 - IMPLANT_PULSE_WIDTH)

#define FREQ_1MHz_IMPLANT_TA0CCR0      60      // (1000000 / IMPLANT_FREQUENCY - 1)

#define FREQ_32kHz_IMPLANT_TA0CCR0     251     // (1000000 / IMPLANT_FREQUENCY - 1)
#define FREQ_32kHz_IMPLANT_TA0CCR1     250     // (1000000 / IMPLANT_FREQUENCY - 1 - IMPLANT_PULSE_WIDTH)

//#define FREQ_32kHz_IMPLANT_TA0CCR0     12000 // (1000000 / IMPLANT_FREQUENCY - 1)
//#define FREQ_32kHz_IMPLANT_TA0CCR1     11999    // (1000000 / IMPLANT_FREQUENCY - 1 - IMPLANT_PULSE_WIDTH)





typedef enum {
    BATTERY_LEVEL_NORMAL,
    BATTERY_LEVEL_LOW
} Battery_Status;

typedef enum {
    CHAN_LEFT,
    CHAN_RIGHT,
} Stimulation_Channel;


typedef enum {
    UNILATERAL,
    BILATERAL
} Stimulation_Type;


typedef enum {
    IMPEDANCE_NORMAL,
    IMPEDANCE_LOW,
    IMPEDANCE_HIGH
} Impedance_Status;


typedef enum {
    CURRENT_LEFT,
    CURRENT_RIGHT,
    COUNTERPULSE_ATTENUATION_LEFT,
    COUNTERPULSE_ATTENUATION_RIGHT,
    VBOOSTER,
    VREF
} Digipot_Function;


typedef enum {
    RESOLUTION_LOW,
    RESOLUTION_HIGH
} Timer_Resolution;
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

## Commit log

2021-08-10 first add
    [Cap.stl, STELLA_RF.brd, STELLA_RF.sch]
2021-10-07 Add Datasets generated by STELLA
    [snex100__current_50uA_brain_no_discharge_resistance.csv, snex100_current_100uA_saline_digital60_resistance.csv, snex100_current_100uA_saline_digital70_resistan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]
2025-11-20 - Move BIST measurement point for each channel to the node before the blocking capacitor - Add a 10 MΩ discharge resistor to each output channel - Replace 100 uF capacitors with 22 uF/16VDC versions 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
    [STELLA.brd, STELLA.sch]
